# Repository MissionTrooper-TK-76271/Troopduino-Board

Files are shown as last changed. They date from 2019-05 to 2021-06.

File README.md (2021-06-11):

# Troopduino-Board
Troopduino Voice Changer and Effects Board

https://github.com/BipeFlyer/Troopduino

This project uses an Arduino nano to create clicks and static when talking.  
Features:
<ul>
  <li>Voice changer
  <ul>
  <li>Bandpass Filter</li>
  <li>Bitcrusher</li>
  <li>Reverb</li>
</ul>
  </li>
  <li>PTT (Push to Talk) Mode</li>
  <li>Voice Activation Mode</li>
  <li>Sound Effects</li>
  <li>Looping Background Effects</li>
</ul>

To Complete this project you will need:
<ul>
  <li>Arduino Nano</li>
  <li>DFPlayer Mini</li>
  <li>OSH Troopduino V1.1
  <li>Adafruit Electret Microphone Amplifier - MAX4466 with Adjustable Gain https://www.adafruit.com/product/1063</li>
  <li>3.5mm Phone Jack	https://www.mouser.ca/ProductDetail/490-MJ-3523-SMT-TR</li>
  <li>C1, C2 Capacitor	https://www.mouser.ca/ProductDetail/603-CC805ZRY5V9BB104</li>
  <li>R1	2.2K Ohm	https://www.mouser.ca/ProductDetail/652-CR0805JW-222ELF</li>
  <li>R2, R4, R5	1K Ohm	https://www.mouser.ca/ProductDetail/652-CR0805JW-102ELF</li>
  <li>R3	1.5K Ohm	https://www.mouser.ca/ProductDetail/652-CR0805JW-152ELF</li>
</ul>

See the BOM for components available at Digikey, Mouser etc.



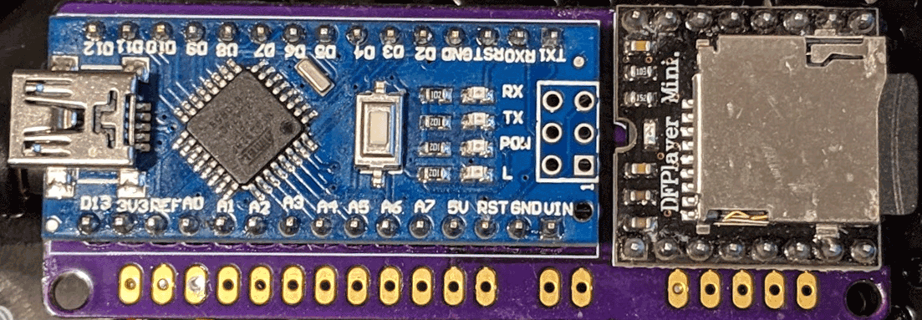
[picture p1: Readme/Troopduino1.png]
Troopduino Board


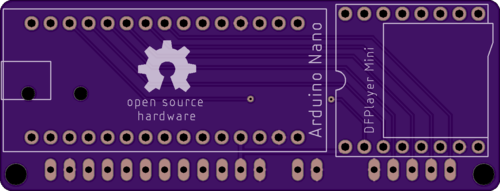
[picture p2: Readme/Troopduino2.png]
Troopduino Board


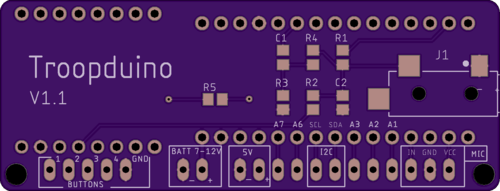
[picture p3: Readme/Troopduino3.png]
Troopduino Board


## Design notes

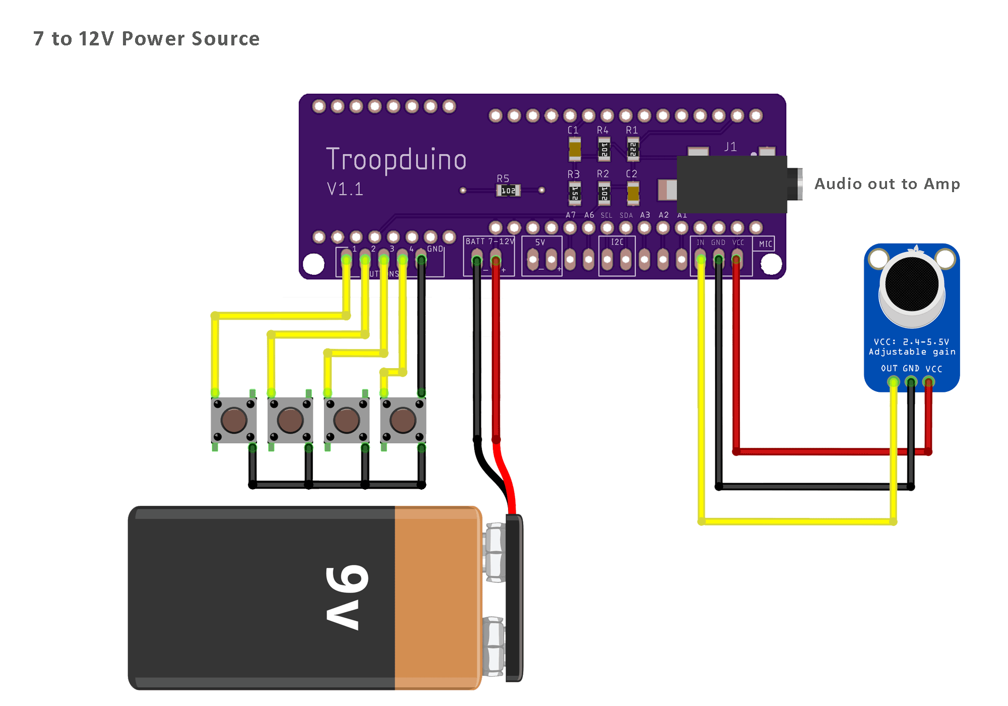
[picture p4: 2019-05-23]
Readme/Connections-7-to-12v.png

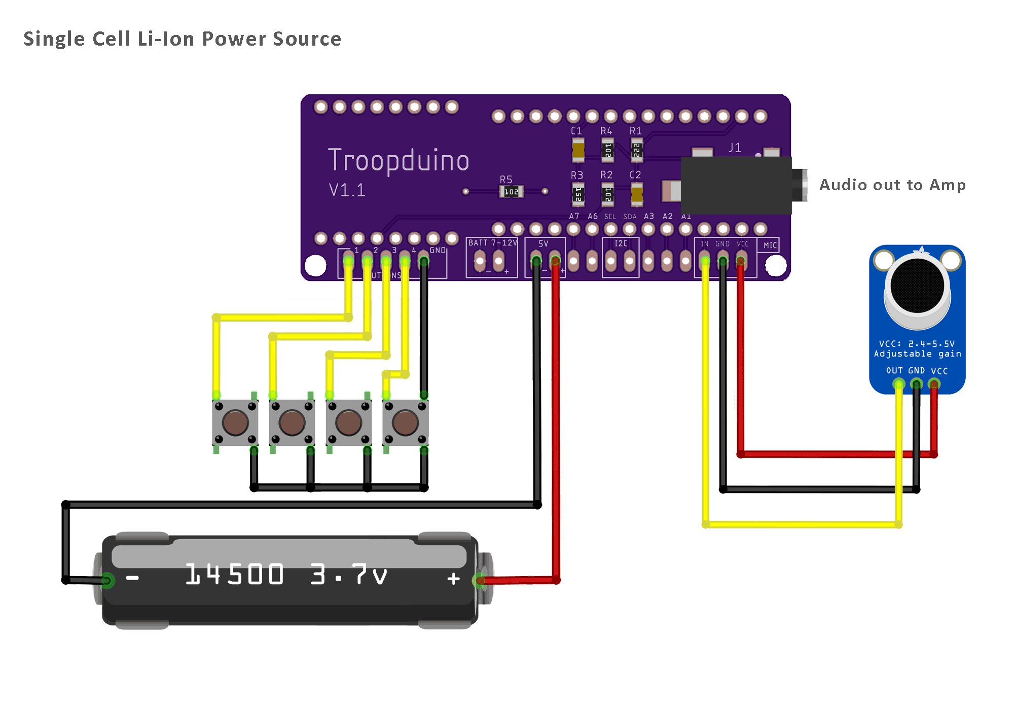
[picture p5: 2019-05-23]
Readme/Connections-Single-Cell-Li-Ion.png

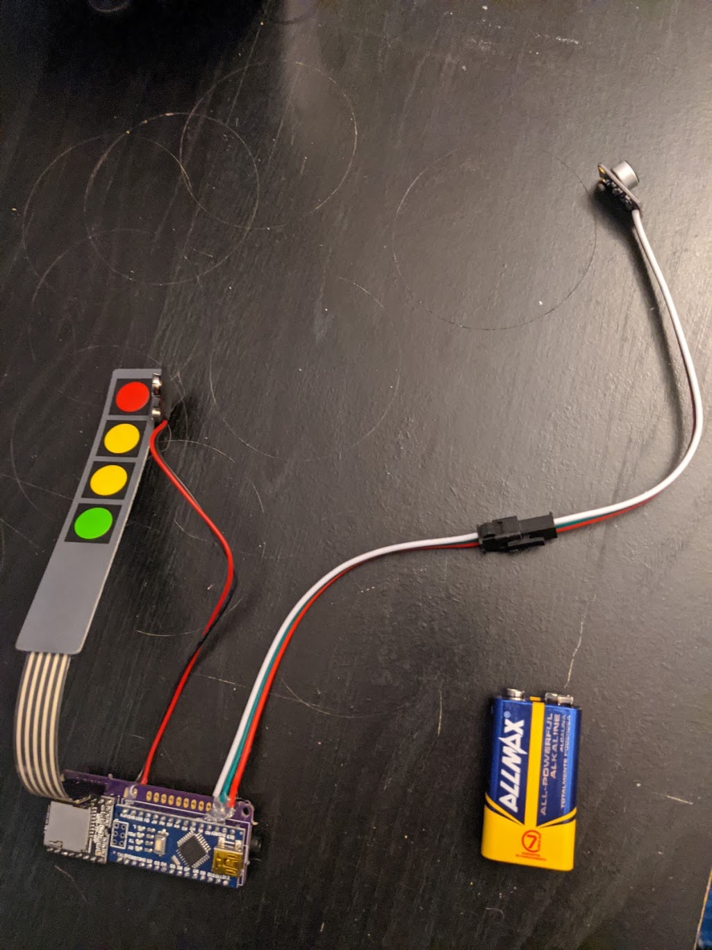
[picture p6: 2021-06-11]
Readme/User_example.jpg

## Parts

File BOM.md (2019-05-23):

<table>
  <tr>
    <td>
      Part
    </td>
    <td>
      Value
    </td>
    <td>
      Package
    </td>
    <td>
      Notes
    </td>
    <td>
      Link
    </td>
  </tr>

  <tr>
    <td>
      C1, C2
    </td>
    <td>
      100nF
    </td>
    <td>
      C0805
    </td>
    <td>
    </td>
    <td>
      https://www.mouser.ca/ProductDetail/603-CC805ZRY5V9BB104
    </td>
  </tr>

  <tr>
    <td>
      R1
    </td>
    <td>
      2.2K Ohm
    </td>
    <td>
      M0805
    </td>
    <td>
    </td>
    <td>
      https://www.mouser.ca/ProductDetail/652-CR0805JW-222ELF
    </td>
  </tr>

  <tr>
    <td>
      R2, R4, R5
    </td>
    <td>
      1K Ohm
    </td>
    <td>
      M0805
    </td>
    <td>
    </td>
    <td>
      https://www.mouser.ca/ProductDetail/652-CR0805JW-102ELF
    </td>
  </tr>

  <tr>
    <td>
      R3
    </td>
    <td>
      1.5K Ohm
    </td>
    <td>
      M0805
    </td>
    <td>
    </td>
    <td>
      https://www.mouser.ca/ProductDetail/652-CR0805JW-152ELF
    </td>
  </tr>

  <tr>
    <td>
      J1
    </td>
    <td>
      MJ&#8209;3523&#8209;SMT
    </td>
    <td>
    </td>
    <td>
       3.5mm Phono Jack
    </td>
    <td>
      https://www.mouser.ca/ProductDetail/490-MJ-3523-SMT-TR
    </td>
  </tr>

  <tr>
    <td>
      Microphone
    </td>
    <td>
      MAX4466
    </td>
    <td>
    </td>
    <td>
      Adafruid Electret Microphone Amplifier - MAX4466 with Adjustable Gain
    </td>
    <td>
      https://www.adafruit.com/product/1063</br>
      https://www.mouser.ca/ProductDetail/485-1063
    </td>
  </tr>

  <tr>
    <td>
      Arduino
    </td>
    <td>
    </td>
    <td>
      Nano
    </td>
    <td>
      Available on Amazon, eBay, DigiKey, Mouser
    </td>
    <td>
      https://www.arduino.cc/en/Guide/ArduinoNano
    </td>
  </tr>

  <tr>
    <td>
      DFPlayer Mini
    </td>
    <td>
    </td>
    <td>
    </td>
    <td>
      Available on Amazon, eBay, DigiKey, Mouser
    </td>
    <td>
      https://www.dfrobot.com/product-1121.html?search=dfplayer
    </td>
  </tr>

</table>

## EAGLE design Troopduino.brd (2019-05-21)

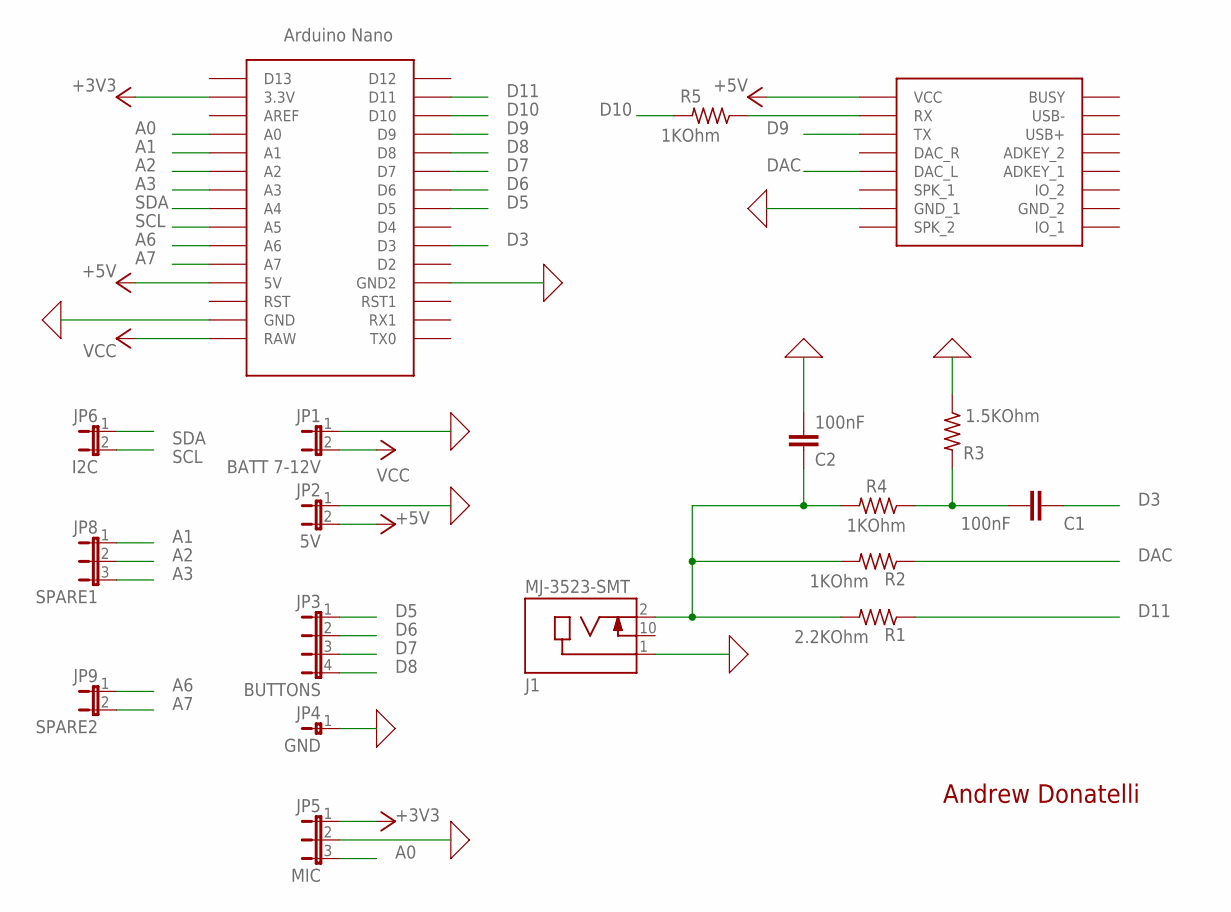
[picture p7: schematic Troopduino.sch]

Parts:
C1, C2: 100nF; C0805
J1: MJ-3523-SMT; CUI_MJ-3523-SMT
JP1: BATT 7-12V; JP1
JP2: 5V; JP1
JP3: BUTTONS; JP4
JP4: GND; JP0
JP5: MIC; JP2
JP6: I2C; JP1
JP8: SPARE1; JP2
JP9: SPARE2; JP1
R1: 2.2KOhm; M0805
R2, R4, R5: 1KOhm; M0805
R3: 1.5KOhm; M0805
U$1: DFPLAYER
U$2: NANO

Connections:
0: C2.1, J1.1, JP1.1, JP2.1, JP4.1, JP5.2, R3.1, U$1.GND_1, U$2.GND, U$2.GND1 (GND2)
+3V3: JP5.1, U$2.3.3V
+5V: JP2.2, U$1.VCC, U$2.5V
A0: JP5.3, U$2.A0
A1: JP8.1, U$2.A1
A2: JP8.2, U$2.A2
A3: JP8.3, U$2.A3
A6: JP9.1, U$2.A6
A7: JP9.2, U$2.A7
D3: C1.1, U$2.D3
D5: JP3.1, U$2.D5
D6: JP3.2, U$2.D6
D7: JP3.3, U$2.D7
D8: JP3.4, U$2.D8
D9: U$1.TX, U$2.D9
D10: R5.2, U$2.D10
D11: R1.1, U$2.D11
DAC: R2.1, U$1.DAC_L
unnamed: R5.1, U$1.RX
unnamed: C1.2, R3.2, R4.1
unnamed: C2.2, J1.2, R1.2, R2.2, R4.2
SCL: JP6.2, U$2.A5
SDA: JP6.1, U$2.A4
VCC: JP1.2, U$2.RAW

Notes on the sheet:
Andrew Donatelli

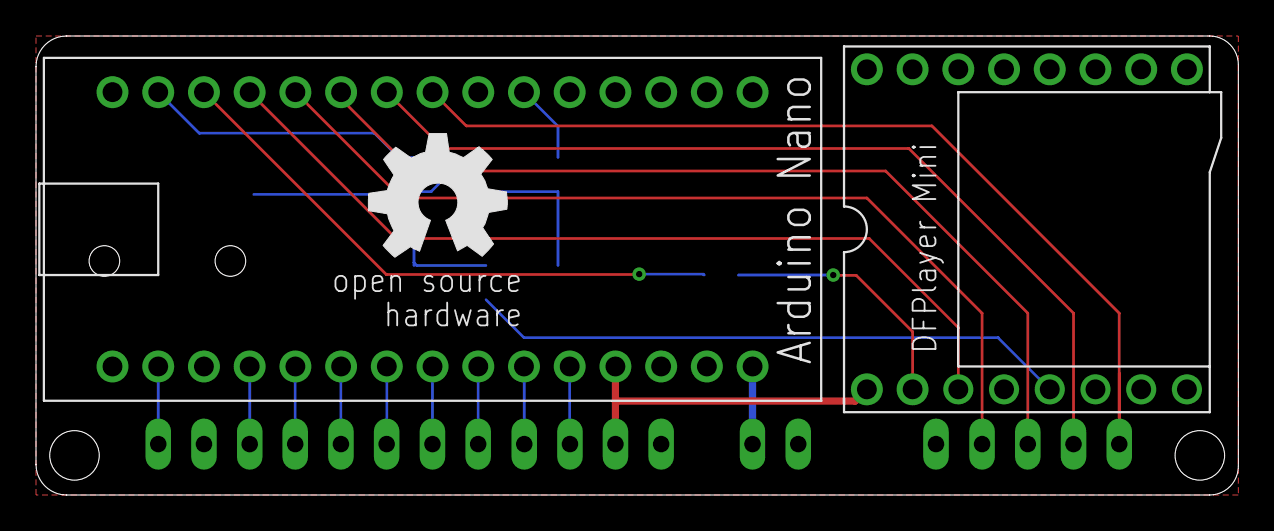
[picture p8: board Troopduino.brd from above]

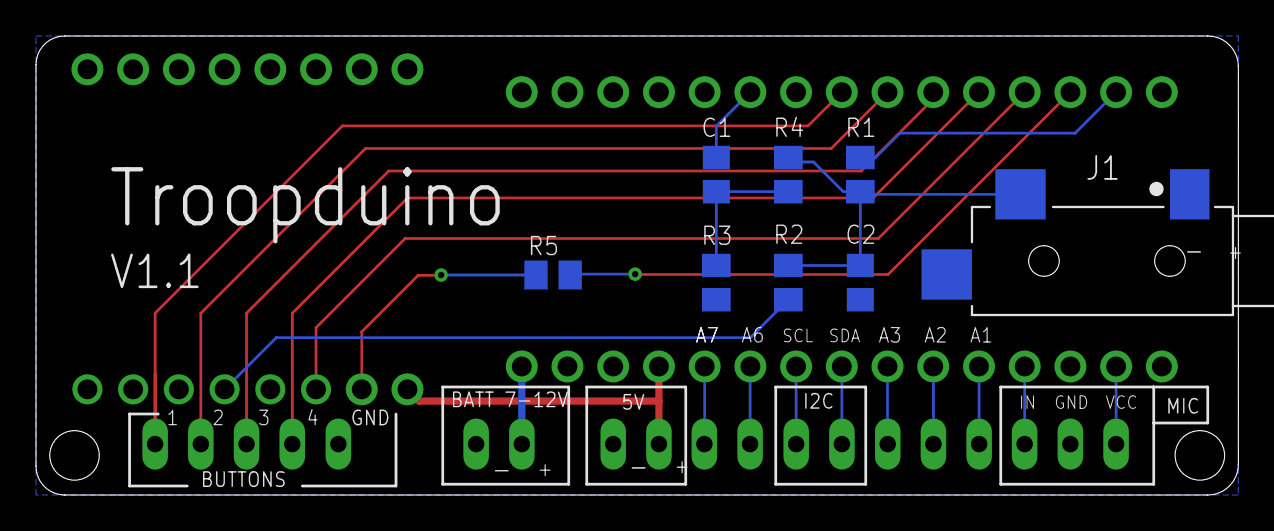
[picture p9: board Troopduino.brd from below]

Board: 2 copper layers, 66.8 x 25.5 mm, 19 parts (16 on the bottom side), 24 nets.

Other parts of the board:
U$3: OSHW_8MM

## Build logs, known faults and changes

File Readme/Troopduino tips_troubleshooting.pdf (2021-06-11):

## Troopduino Troubleshooting

Issues I ran into making my own Troopduino and personal recommendations.

0.) Recommendations

Microphone

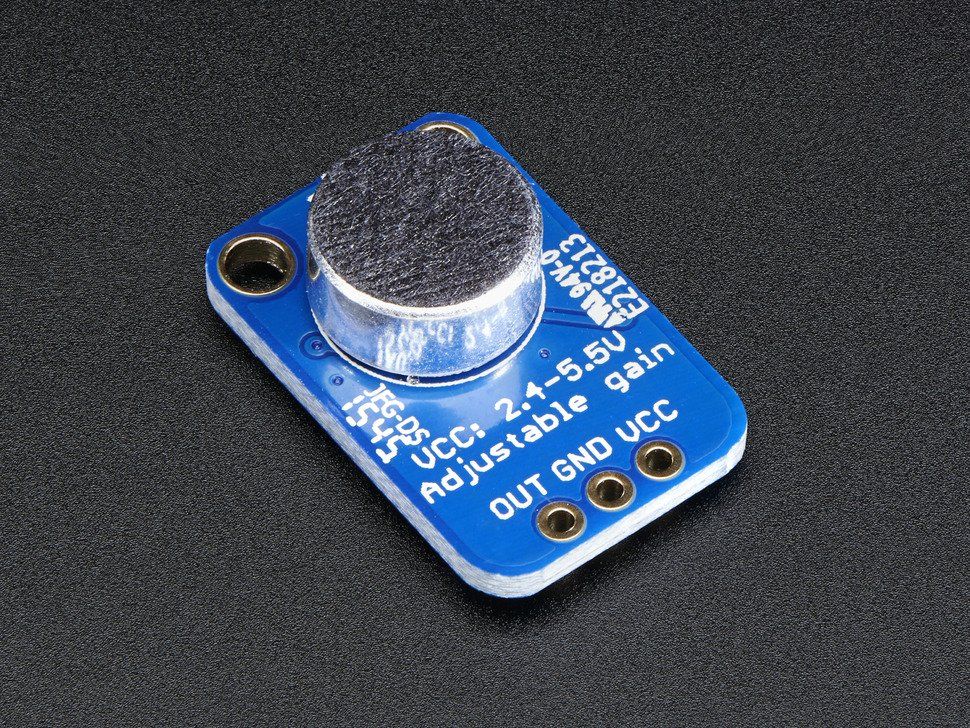
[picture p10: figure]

The microphone is susceptible to moisture and recommend a mic foam cover or wrapping the microphone in thin plastic. This will help avoid wind being picked up and reduce moisture from talking into it.

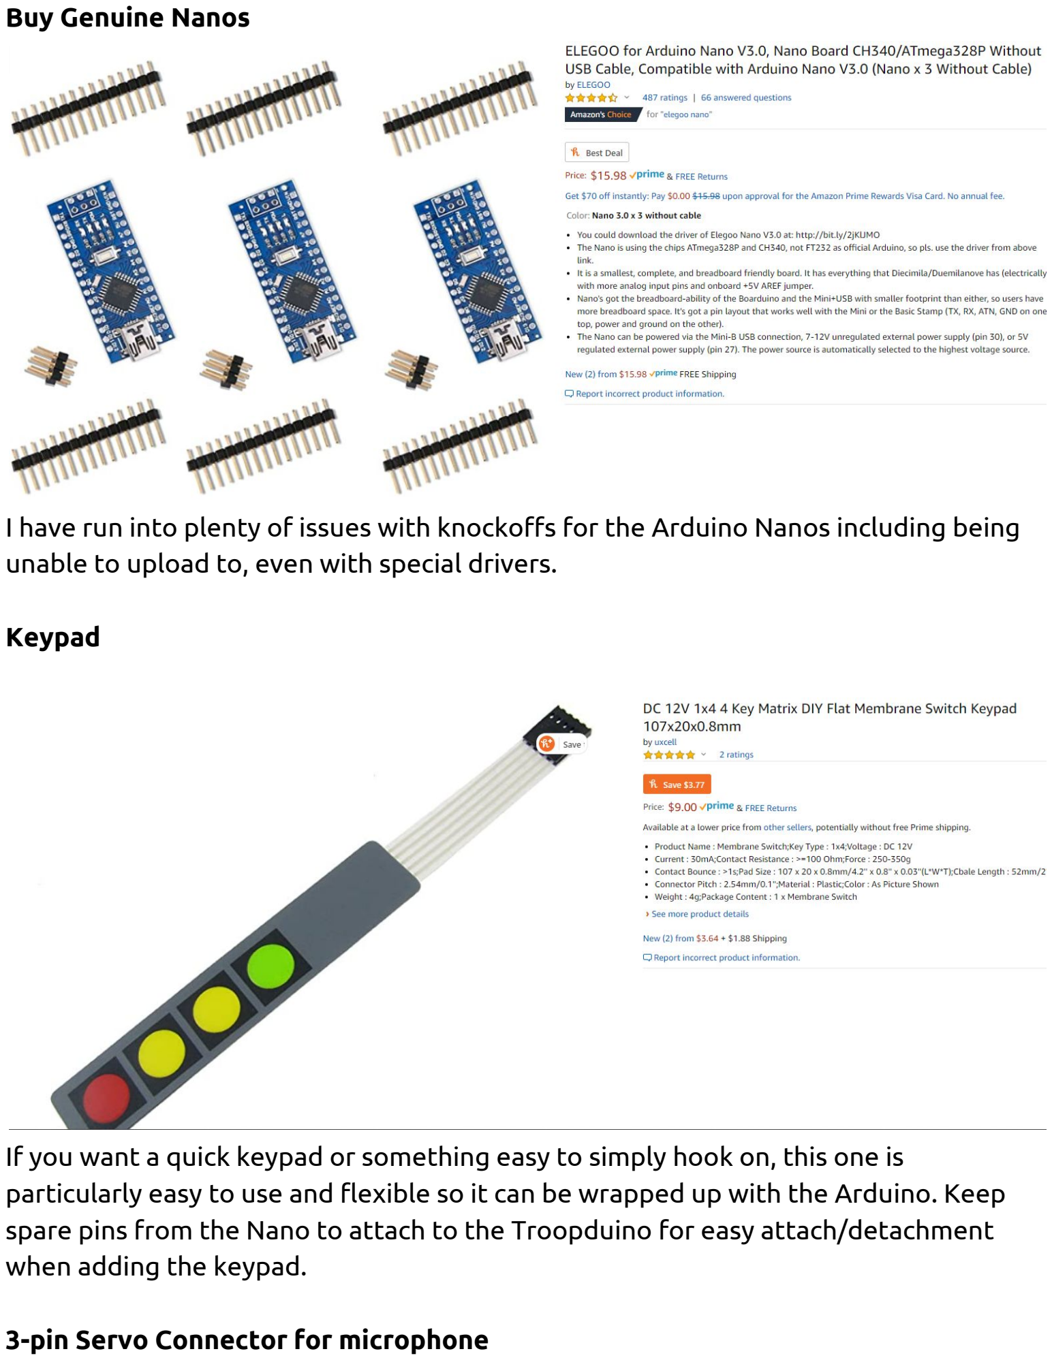
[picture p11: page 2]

Buy Genuine Nanos

I have run into plenty of issues with knockoffs for the Arduino Nanos including being unable to upload to, even with special drivers.

Keypad

If you want a quick keypad or something easy to simply hook on, this one is particularly easy to use and flexible so it can be wrapped up with the Arduino. Keep spare pins from the Nano to attach to the Troopduino for easy attach/detachment when adding the keypad.

3-pin Servo Connector for microphone

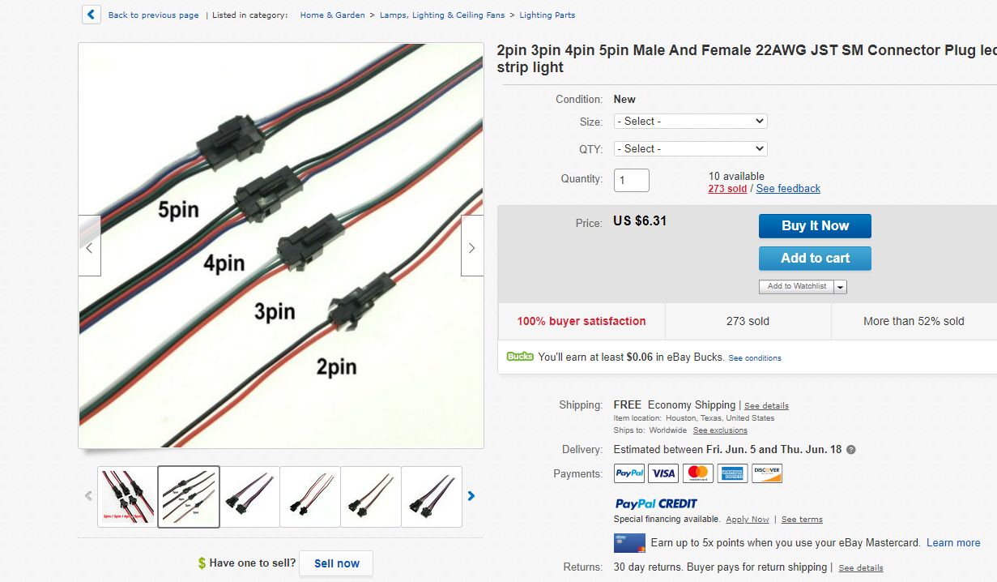
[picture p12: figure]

It allows you to attach a new microphone if it breaks and extend the piece if needed.

1.) Failing to upload to Arduino Nano

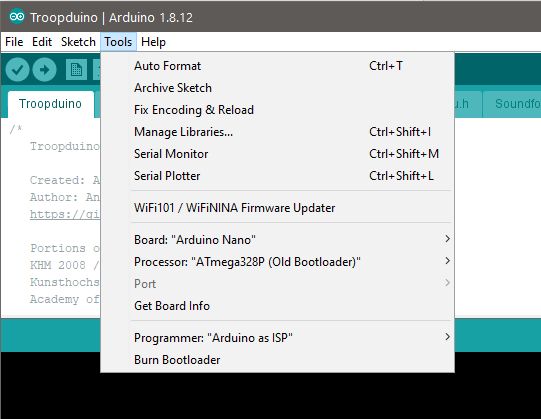
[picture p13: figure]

Board: Arduino Nano selected
Processor: Atmega328P (If you have a genuine Nano) or Old Bootloader if it is an older/knockoff
Port: Make sure it can recognize the connected port (i.e. Port 4, Port 5, etc) and check Device Manager for PORTS to see if the drivers can see the Arduino
Programmer: Arduino as ISP (Have used USBtinyISP in some cases. Make sure to use Upload using programmer if Upload itself is not working)

2.) SD Card not working/being read

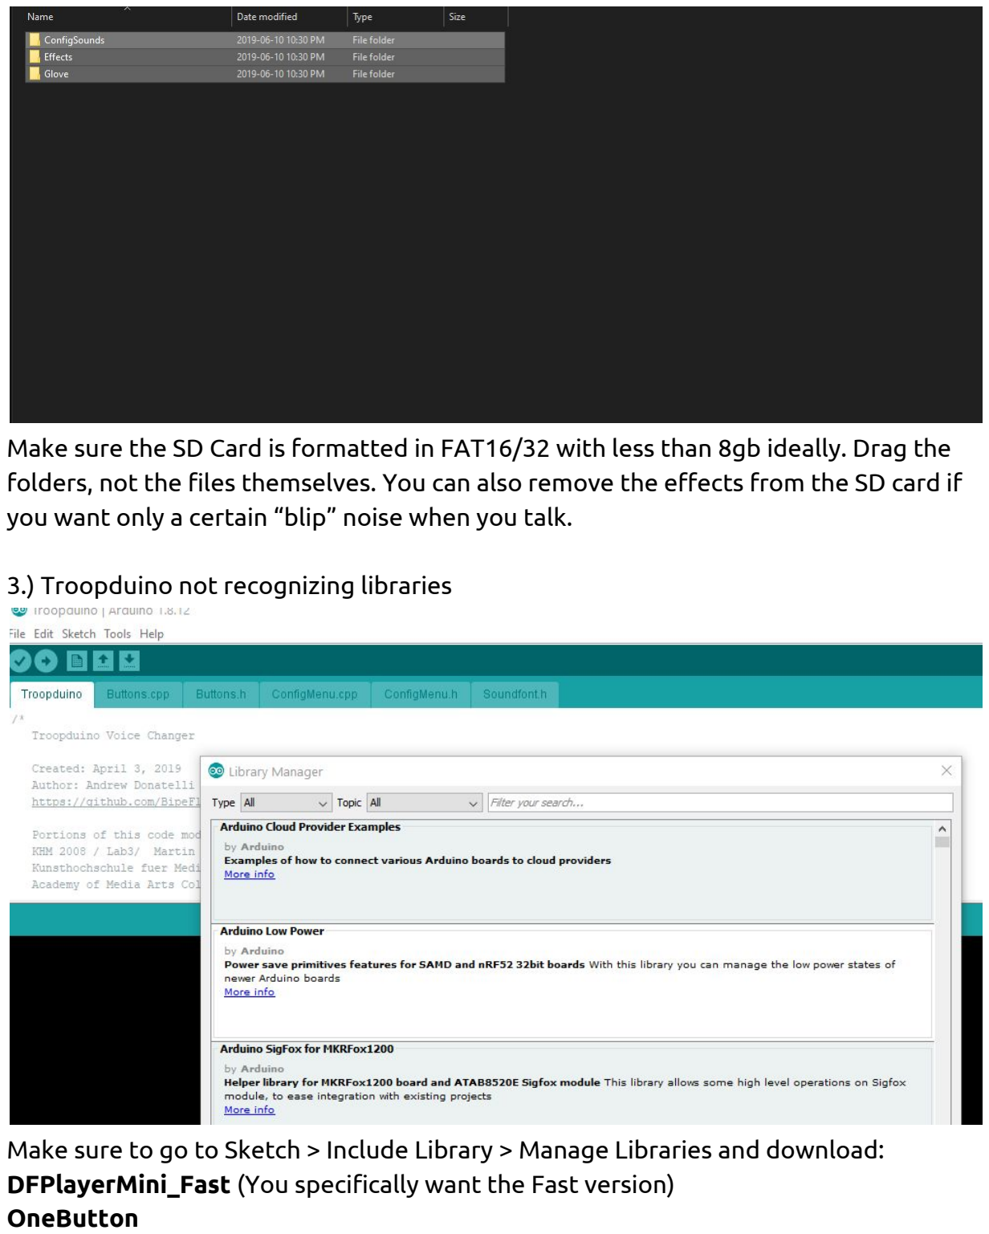
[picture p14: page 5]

Make sure the SD Card is formatted in FAT16/32 with less than 8gb ideally. Drag the folders, not the files themselves. You can also remove the effects from the SD card if you want only a certain “blip” noise when you talk.

3.) Troopduino not recognizing libraries

Make sure to go to Sketch > Include Library > Manage Libraries and download: DFPlayerMini_Fast (You specifically want the Fast version)
OneButton

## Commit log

2019-05-22 Update and rename BOM.txt to BOM.md
2020-06-01 Listed BOM to front
    Friends and I completely missed the BOM pieces for the capacitors and resistors when we built our own. It will be easier to see and recognize as part of the listed parts needed.
